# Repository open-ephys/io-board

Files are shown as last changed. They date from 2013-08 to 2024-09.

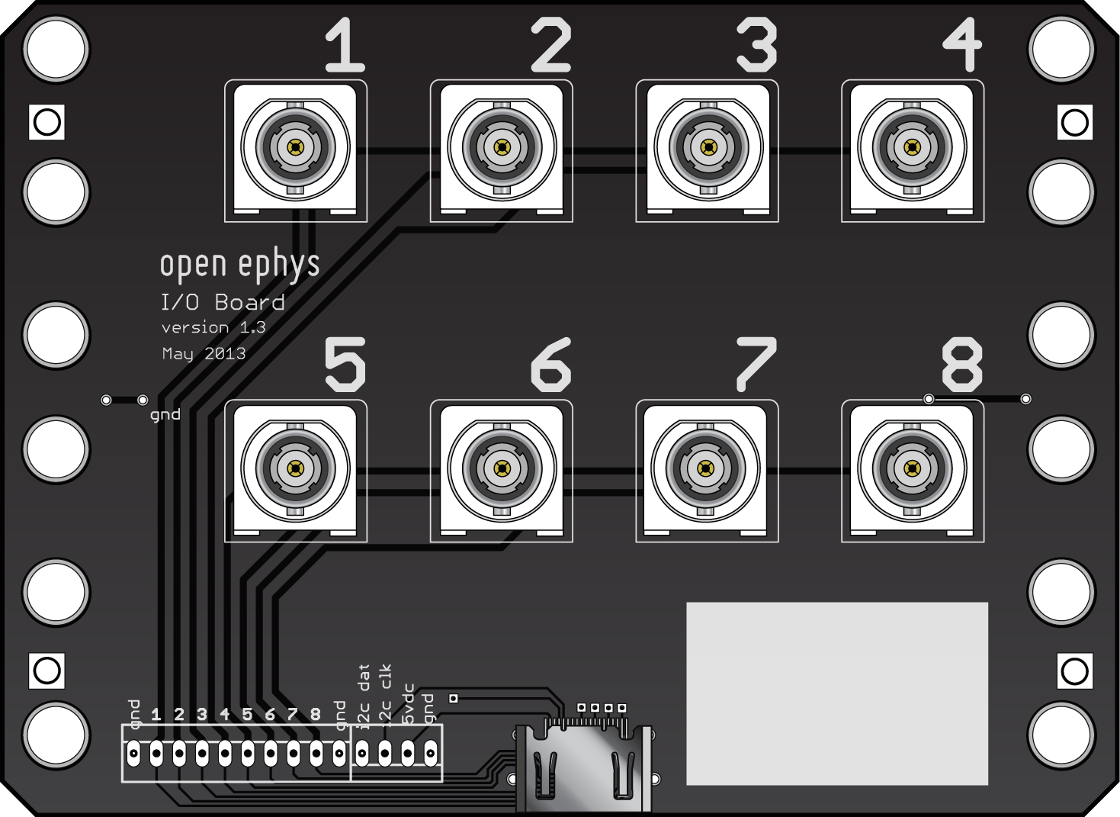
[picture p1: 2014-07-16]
io-board.png

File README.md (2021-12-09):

I/O Board
========

Description
-----------------
Need to sync your neural data with external triggers? Use this board to connect up to 8 digital inputs to the acquisition board. Since its internal components are completely passive, the I/O board can be also be used to relay digital outputs and analog inputs.

Time to build: 1 hour

View on [Open Ephys](https://open-ephys.org/acquisition-system/io-board-pcb)

If you're interested in building your own I/O Board, we strongly recommend getting in touch with us via the Open Ephys [contact](http://open-ephys.com/contact) page.

Specifications
-------------------
- 8 vertical BNC terminals
- HDMI type A connector

Ordering info
-------------------
4.9" x 3.6"

File types:
--------------
- .ai = Adobe Illustrator files; contain images of hardware
- .brd = EAGLE board files; describe the physical layout of the printed circuit board
- .sch = EAGLE schematic files; describe the electrical connections of the printed circuit board
- .cam = EAGLE export files; contain instructions for translating between the .brd file and Gerber files
- BOM.txt = Bill of Materials; contains part numbers for all components (from DigiKey unless otherwise specified)
- .md = Markdown files; most likely a README file; can be viewed with any text edtior
- "gerber" files (.top, .bsk, .oln, etc.) = contain machine-readable instructions for creating the printed circuit board; these are sent to a fab house (such as Sunstone Circuits) for PCB production
- .SLDPRT files = SolidWorks part files; contain CAD models of 3D components
- .STL files = stereolithography files; can be sent to a rapid prototyping service (such as Shapeways) to create 3D objects
- .eps file = encapsulated postscript files; describe the shape of laser-cut parts (Ponoko only). Can be edited in Adobe Illustrator.

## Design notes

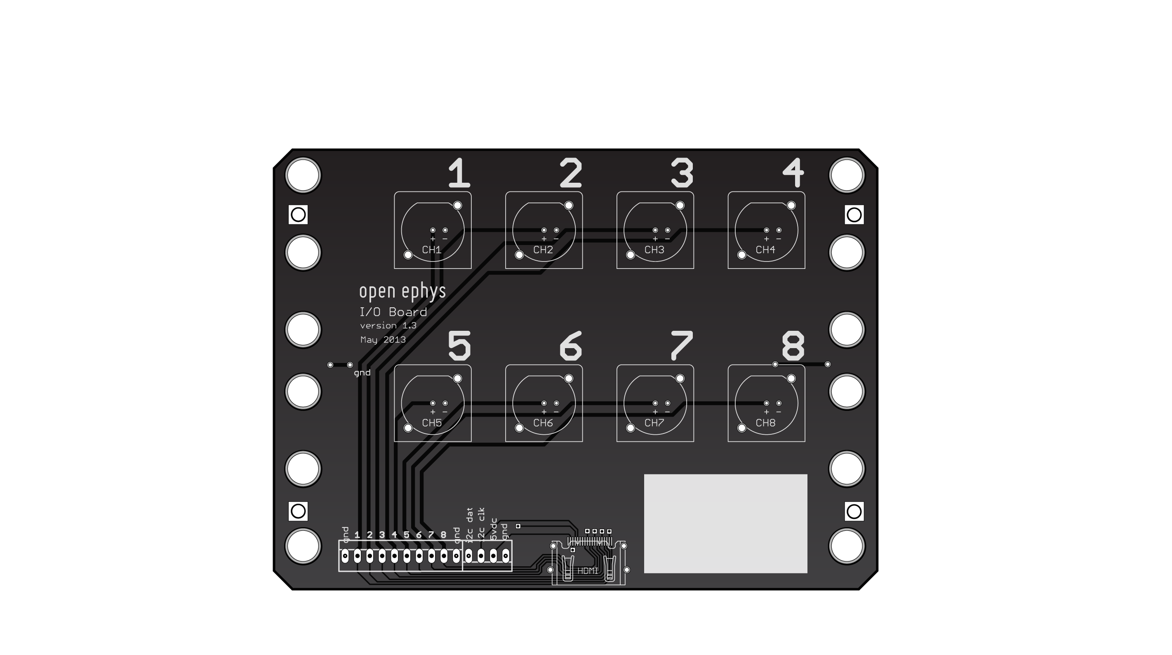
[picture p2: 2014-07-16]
io-board-bare.png

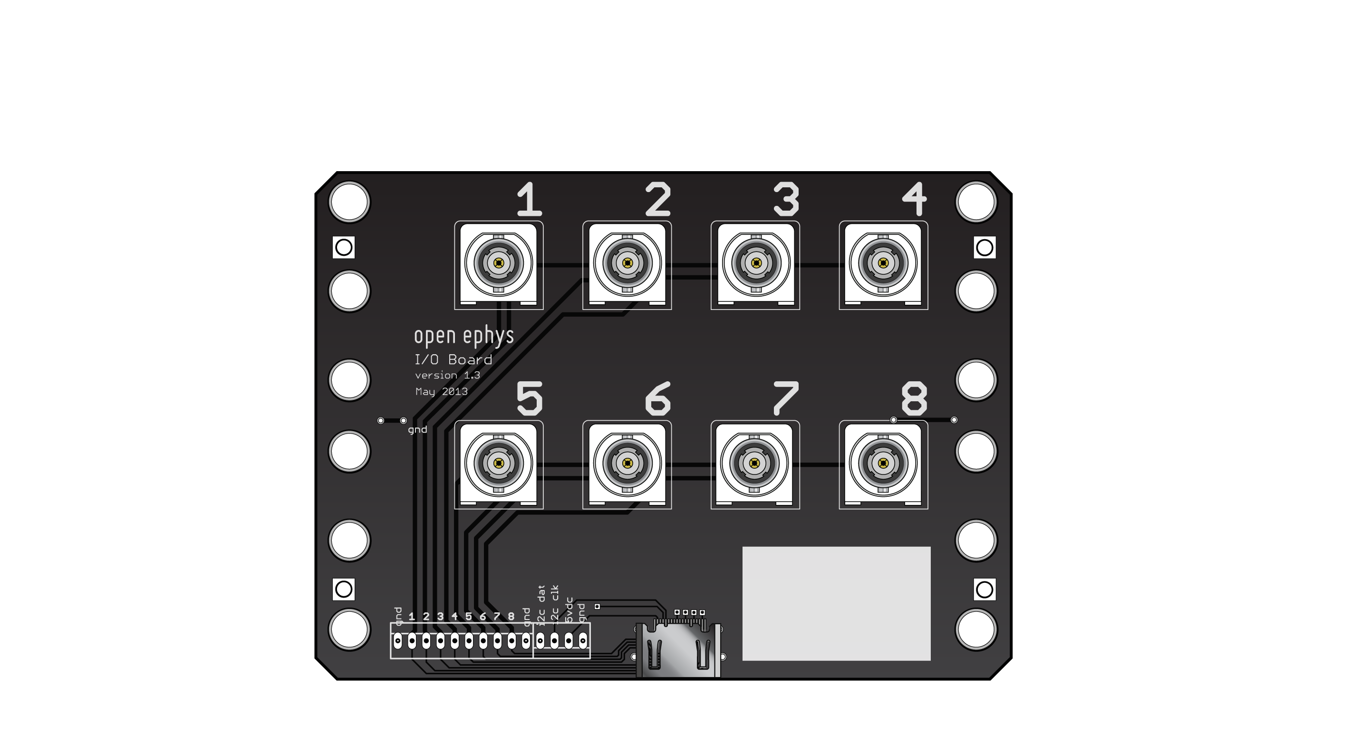
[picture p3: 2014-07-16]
io-board-populated.png

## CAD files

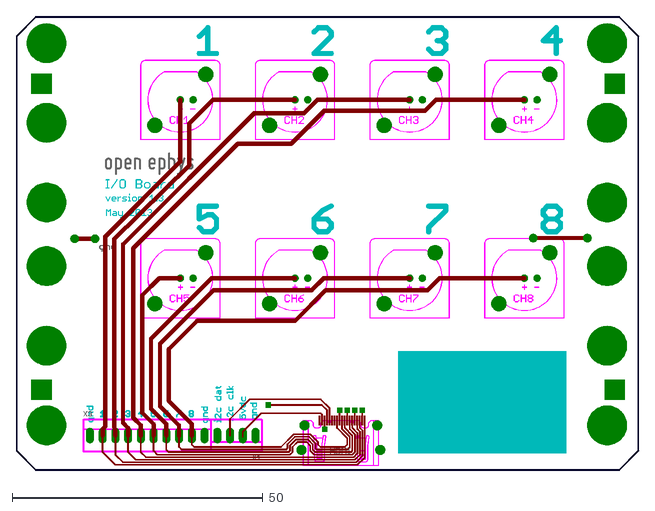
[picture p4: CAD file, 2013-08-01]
io-board.dxf
124.2 x 90.6

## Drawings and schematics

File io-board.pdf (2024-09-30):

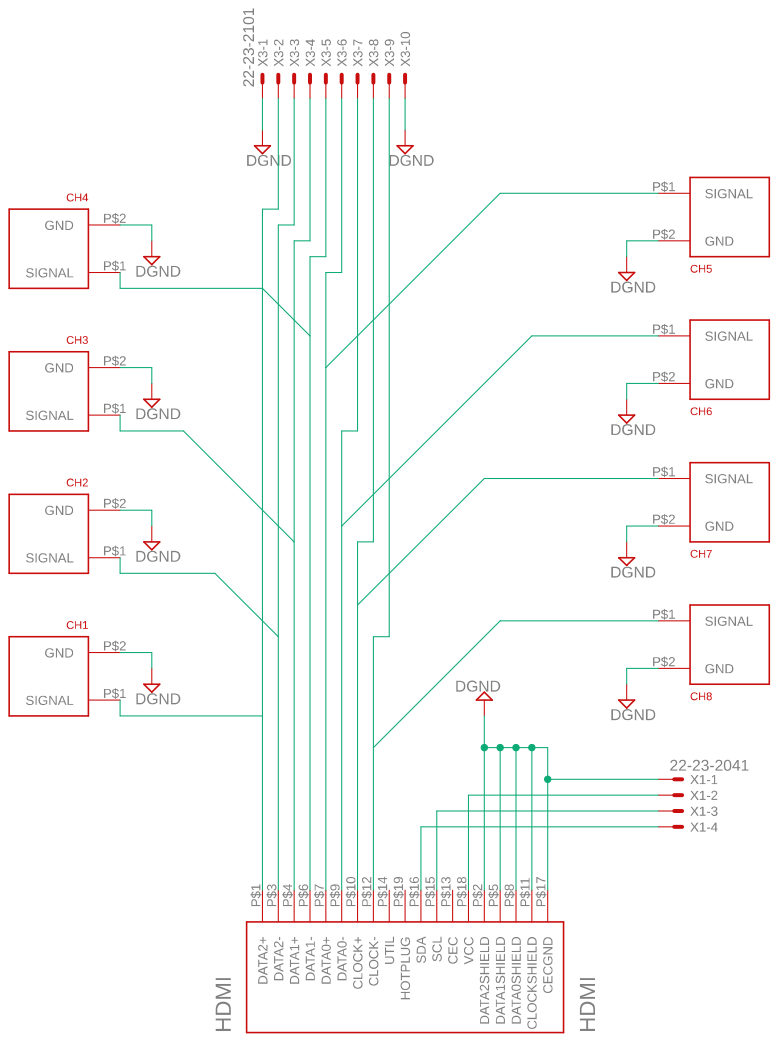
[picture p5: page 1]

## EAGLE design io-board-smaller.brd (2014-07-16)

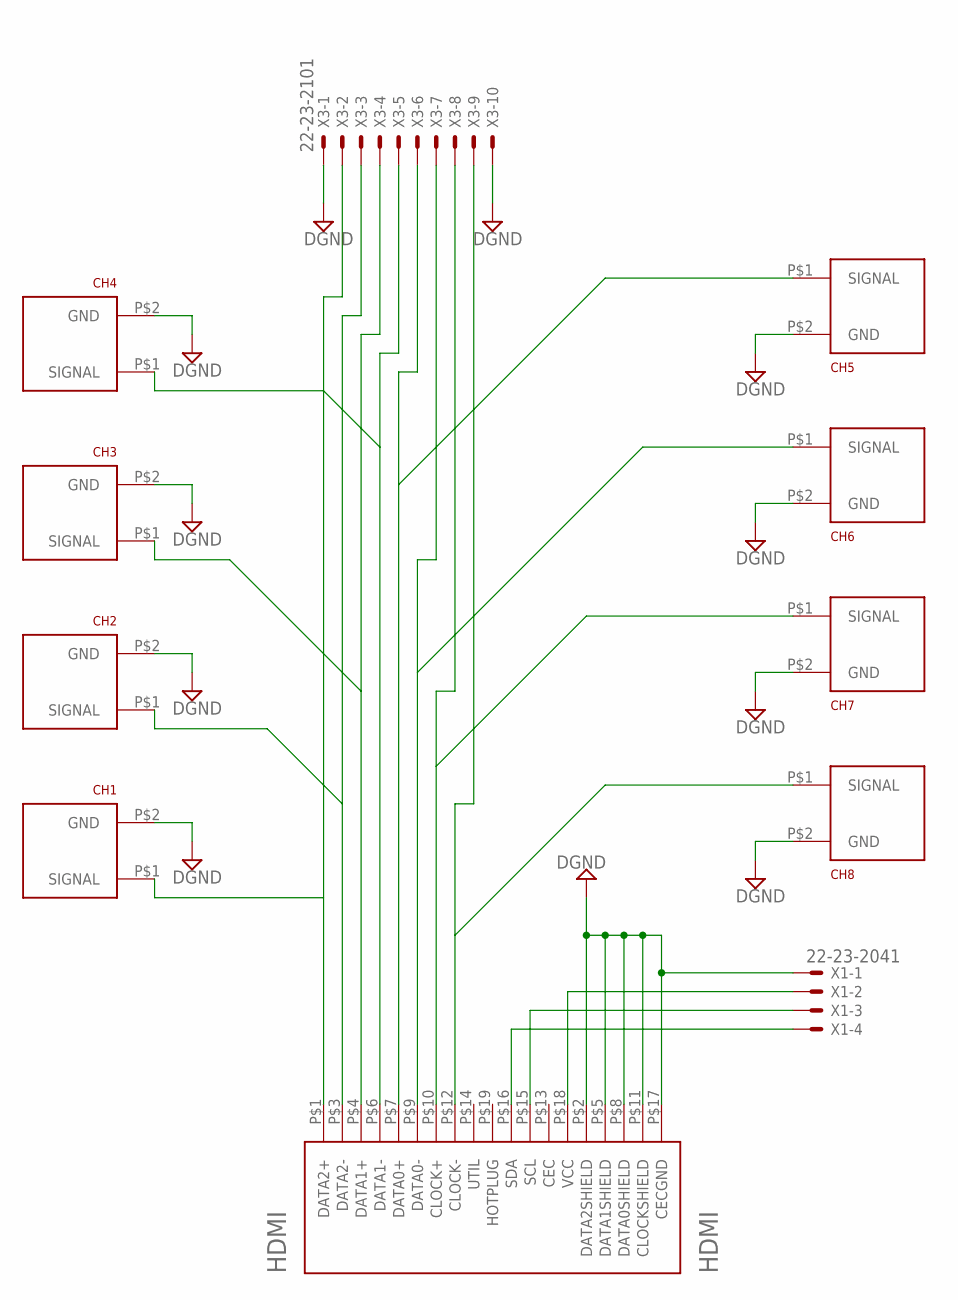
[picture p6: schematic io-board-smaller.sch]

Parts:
CH1, CH2, CH3, CH4, CH5, CH6, CH7, CH8: BNC_VERTICAL
HDMI: HDMI; HDMI_A
X1: 22-23-2041
X3: 22-23-2101

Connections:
CH6: CH6.P$1 (SIGNAL), HDMI.P$9 (DATA0-), X3.7
DGND: CH1.P$2 (GND), CH2.P$2 (GND), CH3.P$2 (GND), CH4.P$2 (GND), CH5.P$2 (GND), CH6.P$2 (GND), CH7.P$2 (GND), CH8.P$2 (GND), HDMI.P$2 (DATA2SHIELD), HDMI.P$5 (DATA1SHIELD), HDMI.P$8 (DATA0SHIELD), HDMI.P$11 (CLOCKSHIELD), HDMI.P$17 (CECGND), X1.1, X3.1, X3.10
I2C_CLK: HDMI.P$15 (SCL), X1.3
I2C_DAT: HDMI.P$16 (SDA), X1.4
unnamed: CH3.P$1 (SIGNAL), HDMI.P$4 (DATA1+), X3.4
unnamed: CH2.P$1 (SIGNAL), HDMI.P$3 (DATA2-), X3.3
unnamed: CH1.P$1 (SIGNAL), HDMI.P$1 (DATA2+), X3.2
unnamed: CH5.P$1 (SIGNAL), HDMI.P$7 (DATA0+), X3.6
unnamed: CH7.P$1 (SIGNAL), HDMI.P$10 (CLOCK+), X3.8
unnamed: CH8.P$1 (SIGNAL), HDMI.P$12 (CLOCK-), X3.9
unnamed: CH4.P$1 (SIGNAL), HDMI.P$6 (DATA1-), X3.5
VCC: HDMI.P$18 (VCC), X1.2

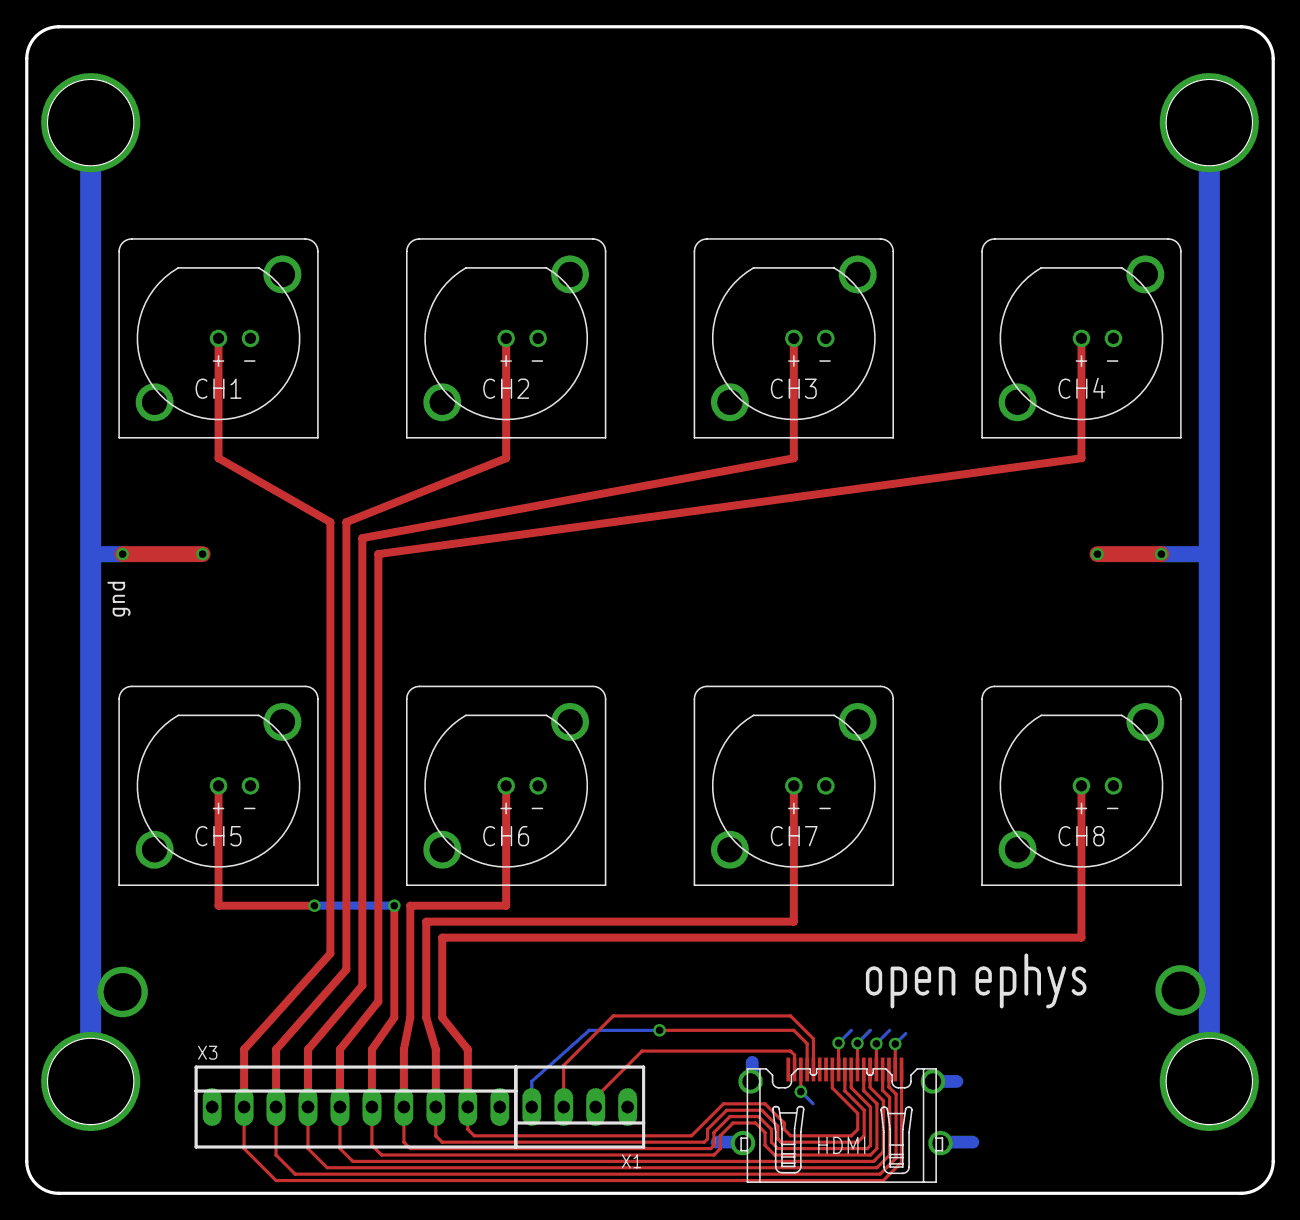
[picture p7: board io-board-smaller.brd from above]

Board: 2 copper layers, 99.1 x 92.7 mm, 12 parts (0 on the bottom side), 12 nets.

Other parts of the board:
U$2: OPEN_EPHYS_LOGO

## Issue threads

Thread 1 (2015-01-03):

No BOM in the repository (?) and wiki erroneously has 75ohm parts listed

cxrodgers, 2015-01-03:
Following up on a discussion on the mailing list ...

The README mentions a BOM but I can't find any in the repository. So we should change the README or add one.

The wiki lists Digikey A97564-ND as the BNC connector, but this is apparently a mistake because it is a 75-ohm connector. Can someone recommend a 50-ohm part with the same footprint? I briefly looked but couldn't find one immediately and so defer to some one with more knowledge.

Finally, I suggest adding Digikey 277-1279-ND as a screw terminal option to the BOM. I *think* it will fit but I haven't tried it yet.

aacuevas, 2015-01-04:
Good catch about the BOM. We'll add one.

Connector impedance matching is not too important at the frequencies the system usually operates, although it's true that it could be better for some relatively fast digital signals. I'd recommend using A97557-ND which is basically the same as the one we have now, but with 50 Ohm impedance.

277-1279-ND should definitely fit, as well as any terminal with 2.54mm (0.1 inch) pitch and no mounting posts.

cxrodgers, 2015-01-13:
I updated the wiki with the 50ohm part and the screw terminal link. BOM would still be nice though.

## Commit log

2012-08-31 Added case files
    [io-board-bottom.SLDPRT, io-board-bottom.STL, io-board-top.SLDPRT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]
2012-09-01 Removed holes from board cover
2013-03-19 added draft for rack-mounted 4x io panel
    [io-board_rackmount.brd, io-board_rackmount.sch]
2013-03-22 changed rackmounted IO board to single 8ch board
    to be used with laser-cut mounting panel, or on its own
    added pin headers for i2c and channels
    [io-board_rackmount.brd, io-board_rackmount.sch]
2013-04-07 Minor changes
    [io-board_rackmount.brd]
2013-05-07 updated .1 inch connector to be linear
    [io-board_rackmount.brd]
2013-05-26 Remove LEDs
    [io-board_rackmount.brd, io-board_rackmount.sch]
2013-05-26 Redo rounting
    [io-board_rackmount.brd]
2013-05-26 Minor fixes
    [io-board_rackmount.brd]
2013-07-30 hole pattern now fits 19" rack
    changed spacing to 0.625, 0.625, 0.5, 0.625, 0.625
    [io-board_rackmount.brd]
2013-07-30 OS X changes
    [io-board_rackmount.brd]
2013-07-30 Restore large holes and add 3 mm holes for mounting a case
    [io-board_rackmount.brd]
2013-07-30 Make rackmount board the default
    [io-board-bottom.SLDPRT, io-board-bottom.STL, io-board-top.SLDPRT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]
2013-07-31 Add new Gerber files
    [io-board.drl]
2013-07-31 Add DXF file
    [io-board.dxf]
2013-07-31 Add Illustrator file
    [io-board.brd, io-board.sch]
2013-08-01 Reverse order of numbers on screw terminals
    [io-board.brd, io-board.dxf]
2013-08-16 Added designs in which IO Board fits within a 10 cm x 10 cm box. Helpful for Fusion PCB service.
    [io-board-smaller.brd, io-board-smaller.sch]
2014-07-16 Add images of bare and populated board
2024-09-30 Add PDF of schematic
